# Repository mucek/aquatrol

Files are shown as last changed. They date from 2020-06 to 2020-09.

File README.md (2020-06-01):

# Aquatrol
## Aquarium controller with pH probe, 3-channel LED controller and much more!
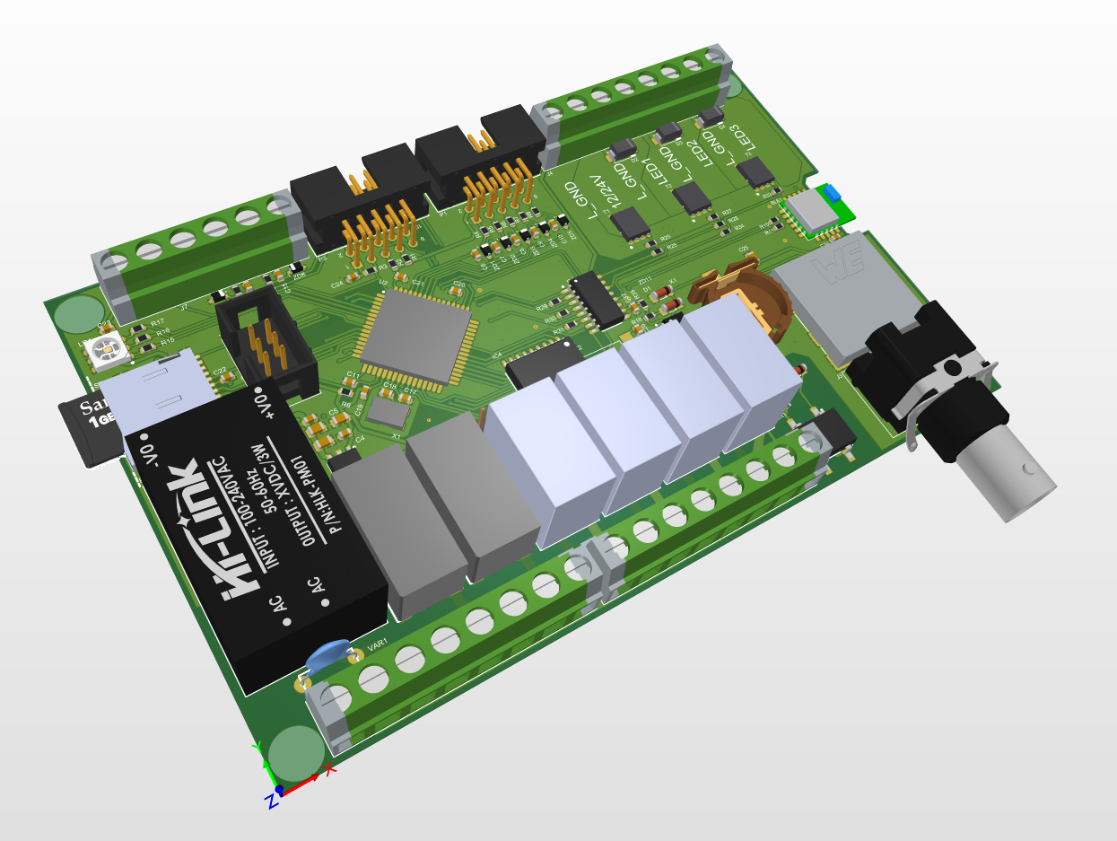
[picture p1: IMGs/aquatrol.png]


## User manuals and quick guide
[User manuals](https://github.com/mucek/aquatrol/blob/master/Docs/_Quickmanual%20aquaTROL.pdf)

[Connection diagram](https://github.com/mucek/aquatrol/blob/master/Docs/Visio-Aquatrol.pdf)

## PCB datasheet
[PCB datasheet (schematics, PCB ...)](https://github.com/mucek/aquatrol/blob/master/PCB/ProductionOutput/Kontroler%20main%20board%201.0_Report.PDF)

## Folder structure:

#### \Android\: Android application (B4A)
#### \Casing\: Casing files
#### \Docs\: Manuals and other documentation
#### \Firmware\: Firmware for the board (Bascom), main program (Aquatrol.hex) and bootloader (BOOT_Aquatrol.hex)
#### \IMGs\: Images
#### \PCB\: PCB project (Altium Designer 20)

## Please write all bugs, feature requests ect. using GitHub's ticketing system! (Issues)

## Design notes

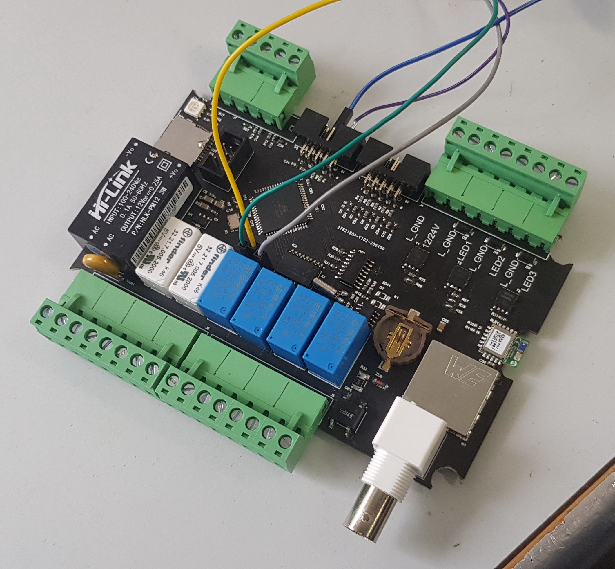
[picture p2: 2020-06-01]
IMGs/2020-05-11 14.08.57.jpg

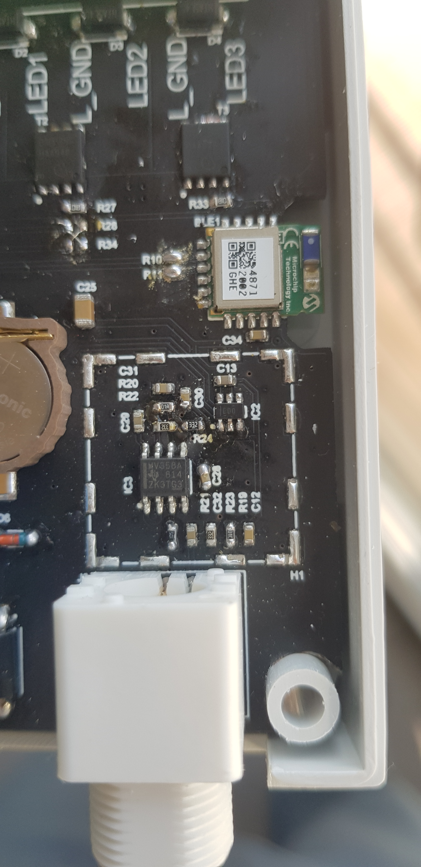
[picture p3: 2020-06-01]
IMGs/2020-05-08 07.53.40.jpg

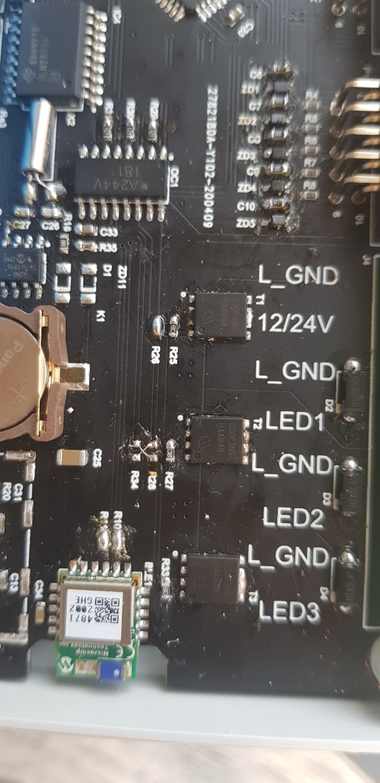
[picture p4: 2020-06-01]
IMGs/2020-05-08 07.53.46.jpg

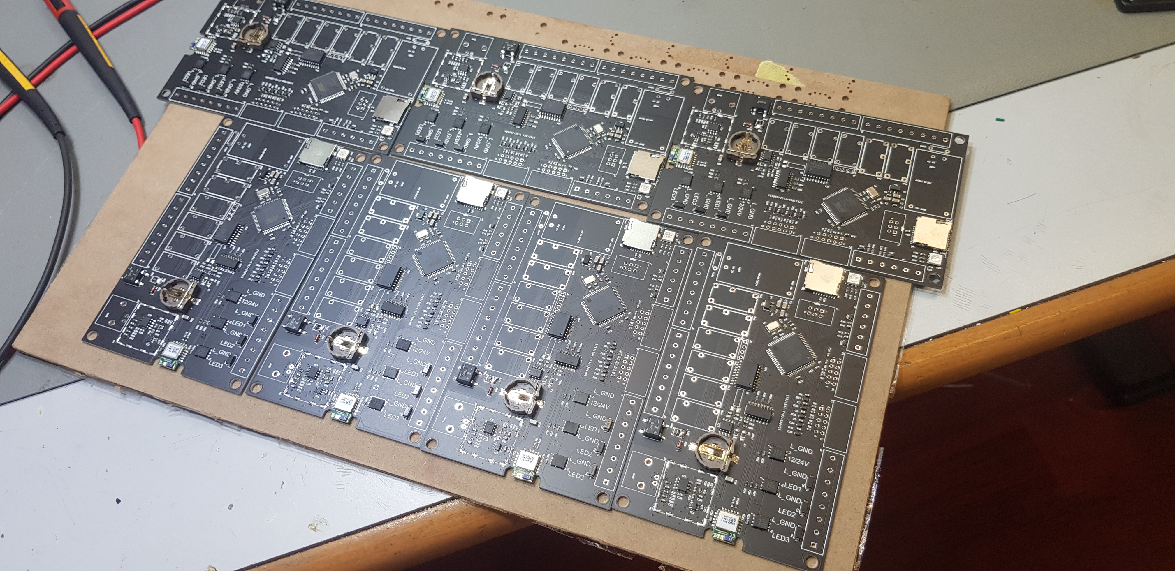
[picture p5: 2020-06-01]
IMGs/2020-05-22 15.17.40.jpg

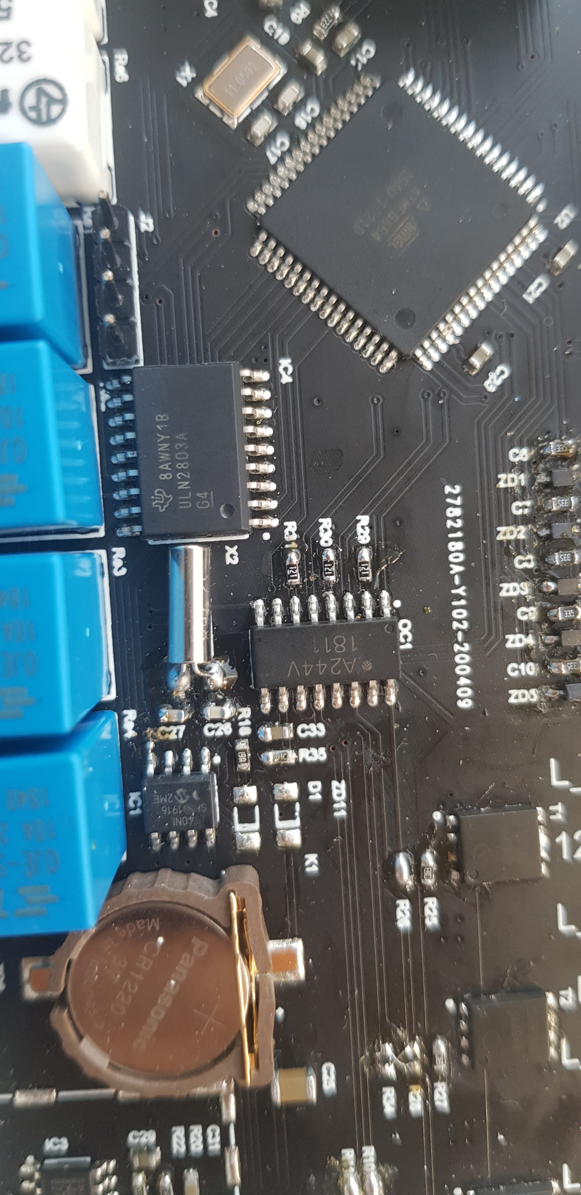
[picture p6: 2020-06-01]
IMGs/2020-05-08 07.53.50.jpg

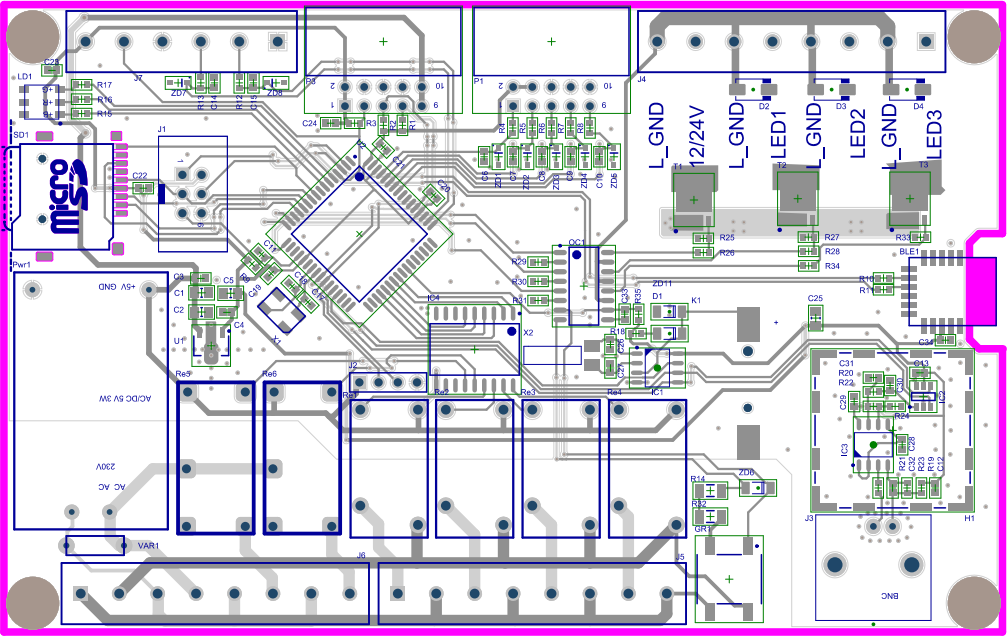
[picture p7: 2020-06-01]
PCB/ProductionOutput/aquatrol.png

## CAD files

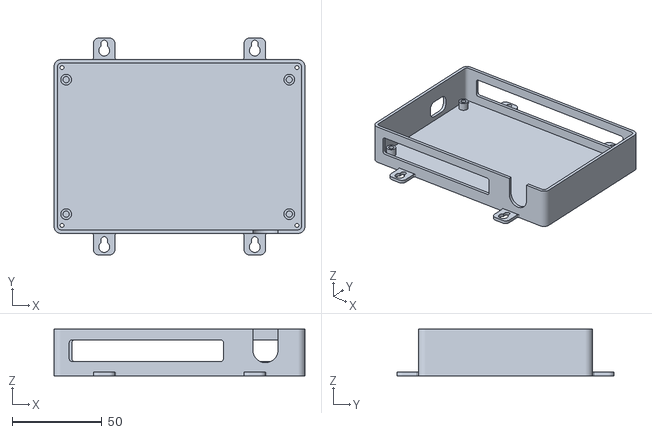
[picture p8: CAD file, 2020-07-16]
Casing/OHISJE-SP-4.stl
140.0 x 121.0 x 26.0

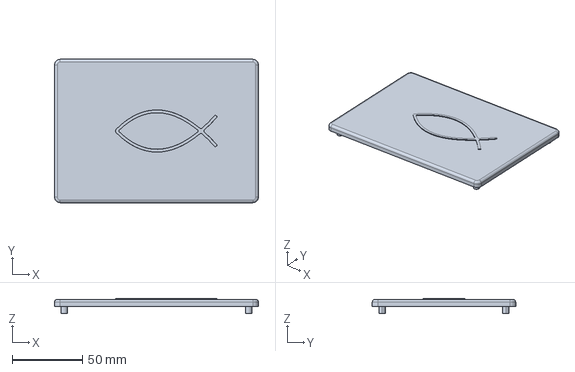
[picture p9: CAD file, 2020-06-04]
Casing/ohisje-zg.stp
145.0 x 102.0 x 10.5 mm

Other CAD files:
Firmware/AquaTrol.obj
Firmware/AquaTrol_HW test.obj
Casing/Z104.dwg
Firmware/BOOT_Aquatrol.obj

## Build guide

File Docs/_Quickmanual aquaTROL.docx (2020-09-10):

# Aquatrol v.1.0 – user manuals

# controller overview

aquaTROL is a dedicated controller for controlling aquarium equipment. Using bluetooth connection it is possible to view status and adjust parameters. Using internal microSD card it is possible also to log data on SD card, adjust settings as well as update firmware.

## Main functions

- LED lights controlling (3 independent channels)
  - Adjustable LED power (255 steps)
  - Sunset and sunrise with adjustable parameters
  - Programmed on/off time, based on internal clock
  - Possible to turn on/off lights using button (night cleaning etc.)
  - Internal clock with backup battery
  - Galvanically seperated outputs, which support 12/24 VDC power supply (external)
  - Max. 4 A / each channel (100 W per channel, 300 W total)
- Heater controlling
  - 230 VAC output to control heater using DS18B20 temperature probe
  - In case of using heater with internal thermostat, we suggest using Aquatrol as main heater controller and adjusting heater's thermostat to 2-3 degrees higher temperature to use it as backup turn-off mechanism.
  - Max. 10 A/230 VAC
- Skimmer controlling
  - 230 VAC output to control turn on skimmer twice per day (adjustable intervals)
  - Max. 10A/230VAC
- CO2 valve controlling using pH probe
  - 230 VAC output for CO2 valve
  - Max. 10A/230VAC
- Filter pumps controlling (2)
  - 2 independent NC channels
  - Max. 6A/230 VAC
  - »FEED« function: when feeding, pump(s) is disabled for a certain period of time (0-999 s)
  - »UPS BACKUP« function: when running on UPS, pumps are switched on alternately in 15 min intervals, so both filters are active and bacterias survive, but power consumption is low.
- 1 auxilary output (10A/230VAC), function will be defined
- Data logging to SD card
  - Data logging on each action; i.e. lights on, CO2 valva off … (/LOG/DATA.TXT)
  - Periodically logging of all parameters to CSV file (/LOG/LOG.TXT), which can be later processed in Excel
- Parameters setup using file on SD card
  - /CONFIG/CONFIG.TXT
- Firmware update using SD card
  - Copy »AquaTrol.hex« file to root folder on SD card
  - Insert card to controller, power on the system and wait 20 s
  - Turn off the controller
  - Remove card and delete file after upgrade

# CONNECTING THE CONTROLLER

Warning! There is a mains voltage on the controller! Be careful and first disconnect the power supply cable before doing anything on the controller itself!

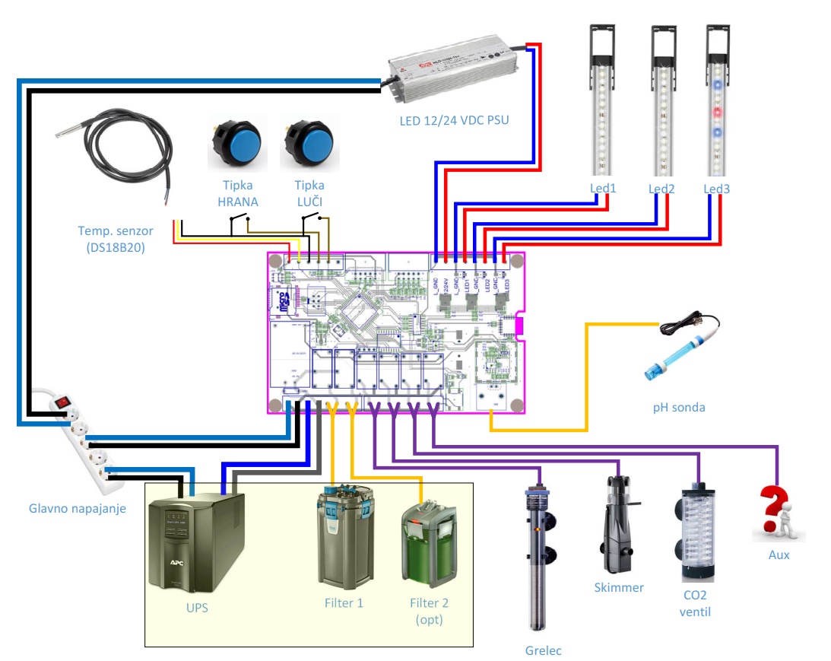
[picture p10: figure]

1) Prepare mains cable 230 VAC. Do not connect cable to the power outlet yet!
2) Prepare mains cable for UPS (if used). UPS is used to power controller logic and both filters. All other devices are powered through mains power and in case that mains is disconnected are shut off.
  a. If UPS is not used, short pins 1+3 and 2+4!

Do not connect cable to the UPS yet!

3) Prepare connectors to all equipment used.
  a. If only one filter is used, connect it to left output (1).
4) Connect LED power supply. Mind the correct polarity! Do not connect cable to the power outlet yet!
5) Connect LED diodes to outputs 1-3. Mind the correct polarity!
6) Connect temperature sensor (if used).
7) Connect buttons (if used).
8) Connect pH probe (if used).
9) Insert microSD card (FAT32).
10) Activate UPS power supply. Controller should turn on (see LED diode on it above SD card).
11) Activate mains power supply (230 VAC).
12) Activate LED power supply.

# PARAMETERS SETUP

Parameters are stored in internal EEPROM memory as well as on SD card. If SD card is inserted, data from SD will always be used and copied to EEPROM as well. If no SD card is present, data from EEPROM will be used.

Disconnect UPS 230 VAC power supply. Remove microSD card and insert it into computer. There is a file CONFIG.TXT in the CONFIG folder with following content:

AquaTROL BASIC SETTINGS

/Edit only values, keep formatting!!!/

_________LED 1:__________

255 - power on (000-255)

000 - power off (000-255)

11:00:00 - on time

19:00:00 - off time

1000 - Dimming Step 1(0100-9999)

_________LED 2:__________

254 - power on (000-255)

001 - power off (000-255)

11:15:00 - on time

18:50:00 - off time

1000 - Dimming Step 2(0100-9999)

_________LED 3:__________

255 - power on (000-255)

002 - power off (000-255)

09:00:00 - on time

20:00:00 - off time

1000 - Dimming Step 3(0100-9999)

_______TEMPERATURE_______

251 - target temperature (x.xx)

_________SKIMMER_________

10:00:05 - on time 1

10:15:05 - off time 1

16:00:06 - on time 2

16:15:06 - off time 2

_________CO2 VALVE_______

6.51 - target pH (x.xx)

________FEED TIME________

300 - feed time in s (xxx)

1 - pumps affected (0,1,2)

LED channel 1 settings (left)

Day power (000-255, 255=100%)

Night power (000-255, 0=off)

Sunrise time (time, when sunrise starts)

Sunset time (time, when sunset starts)

Sunset and sunrise speed (1000 approx 15 min)

LED channel 2 settings (middle)

LED channel 3 settings (right)

Heater target temperature

(hysteresis set to 0,2 degrees Celsius)

Skimmer on time 1

Skimmer off time 1

Skimmer on time 2

Skimmer off time 2

CO2 valve pH setting

(hysteresis set to 0,1 pH)

Filter disable when feeding

Feeding time – filter disabling in seconds

0-disabled, 1-filter 1 only, 2-both filters

You may change all values, but keep in mind, that you must not change formatting (i.e. write 100 instead of 0100 or insert/delete some line(s).

# TIME AND DATE CHANGING (rtc)

Create file TIME.TXT using notepad. Its content should be exactly in following format:

12:32:00 04/06/20 | Time Date

When system will startup, file will be read and RTC time will be updated. File will be deleted automatically.

# pH probe calibration

As pH probes are different and they also degenerate with time, it is reccomended to do a periodical calibration each 3-6 months. However at first use pH probe calibration is neccessary for proper readings!

## Requirements

- Aquatrol & pH probe with BNC connector (obviously 😉)
- A glass of tap water (to clean the probe)
- A pH buffer solution with pH=7,0
- A pH buffer solution with pH=4,0
- Smartphone with terminal (Microchip Bluetooth Data or BLT), that works (shows logs each few seconds)

## A step by step guide

1. Connect the pH probe to BNC
2. Put BNC probe to tap water
3. Connect to Aquatrol using terminal
  - Start the app
  - Select BM 70
  - Scan devices and click Aquatrol_xxxx, when found
  - Wait few seconds and click »Transfer data to device«
  - You shall receive periodical readings from the Aquatrol now into top window
  - Click » Send CR/LF« checkbox
  - Write »c« (small letter!) into send window and click »Send«
  - Follow the onscreen manuals for calibration!
4. Put probe into pH=7,0 buffer solution and wait as requested
5. Put probe into tap water to clean it as requested
6. Put probe into pH=4,0 buffer solution and wait as requested
7. Calibrating is finished, clean probe with tap water before putting it to aquarium!

# Teminal commands (change settings via bluetooth)

By default, parameters from SD card are used. At each system startup, data from SD card are also stored into internal memory, so system is operational also if SD card is not inserted.

Some parameters can also be changed through bluetooth terminal, however they are not stored on the SD card, but on internal memory. In case, that internal memory should be used with SD card present (i.e. for logging), a special command must be sent through terminal as described later.

Use only small letters, text is case sensitive!

Command | Syntax | Description | Example

Lights commands

pH probe
cala | | Start automatic pH probe calibration | cala +CR/LF
cals | | Set manual step for 1 pH | cals=0.1020 +CR/LF
cal7 | | Set manual voltage for pH 7 | cal7=0.8525 +CR/LF
feed | | Start Feed cycle | feed +CR/LF
lamp | | Turn LEDs on/off | lamp +CR/LF
help | | Print out all commands | help +CR/LF
pars | | Print out all parameters | pars +CR/LF

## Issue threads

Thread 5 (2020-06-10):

Indikacija ročnega vklopa/izklopa LED in hranjenja

mucek, 2020-06-10:
RGB LED indicira vklop/izklop funkcije:
LED: zelena vklop, oranžna izklop
HRANJENJE: rdeča LED, dokler so pumpe izklopljene

mucek, 2020-06-10:
Narejeno  1 , 0 , 501

Closed 2020-06-10.

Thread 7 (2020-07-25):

Vprašajčki v Terminal Feedu

umetnic, 2020-07-25:
FW: v.1.0.605
**LOG.TXT**; _Se zdi v redu..._

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

**[Microchip Bluetooth Data Export](https://play.google.com/store/apps/details?id=com.microchip.bluetooth.data):**
_Vprašajčki na drugih točkah kot v naslednjem app-u_
video: https://www.youtube.com/embed/q5NsGTYWXBU
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

**[Serial Bluetooth Terminal Export](https://play.google.com/store/apps/details?id=de.kai_morich.serial_bluetooth_terminal):**
_Vprašajčki so konstantni znotraj enega connectiona, pri naslednjem pa so drugje.._
08:48:56.577 Connecting to AquaTrol_C1E7 ...
08:49:01.802 Connection failed: gatt status 133
08:49:06.714 Connecting to AquaTrol_C1E7 ...
08:49:11.887 Connection failed: gatt status 133
08:49:21.716 Connecting to AquaTrol_C1E7 ...
08:49:24.901 **Connected**
08:49:25.896
08:49:27.186
08:49:27.248
08:49:27.248 25/07/20 08:53:09
08:49:27.248 Fltr�� ^@s:0(t=0)
08:49:27.248 Fltr2_dis:0(t=0)
08:49:27.248 Heater:0(248/252)
08:49:27.248 Skimmer:0 10:00:00/10:15:00, 16:00:00/16:15:00
08:49:27.248 CO2 valve:1(6.5000)
08:49:27.248 Aux:0
08:49:27.248 Led1:0/255, 255@11:00:00/0@19:00:00
08:49:27.307 Led2:0/255, 255@11:15:00/0@18:50:00
08:49:27.307 Led3:0/255, 255@09:00:00/0@20:00:00
08:49:27.307
08:49:27.307 pH :7.6006(U=1.7139V)
08:49:27.307 Temp :253oC
08:49:27.307 AC OK:1
08:49:27.366 IN1 feed:0(300s)
08:49:27.366 IN2 light:0(step 1000)
08:49:28.205
08:49:29.196
08:49:30.216
08:49:31.241
08:49:31.298
08:49:31.298 25/07/20 08:53:13
08:49:31.298 Fltr�� ^@s:0(t=0)
08:49:31.298 Fltr2_dis:0(t=0)
08:49:31.298 Heater:0(248/252)
08:49:31.298 Skimmer:0 10:00:00/10:15:00, 16:00:00/16:15:00
08:49:31.298 CO2 valve:1(6.5000)
08:49:31.298 Aux:0
08:49:31.298 Led1:0/255, 255@11:00:00/0@19:00:00
08:49:31.359 Led2:0/255, 255@11:15:00/0@18:50:00
08:49:31.359 Led3:0/255, 255@09:00:00/0@20:00:00
08:49:31.359
08:49:31.359 pH :7.6006(U=1.7139V)
08:49:31.359 Temp :253oC
08:49:31.359 AC OK:1
08:49:31.417 IN1 feed:0(300s)
08:49:31.417 IN2 light:0(step 1000)
...
08:50:01.418
08:50:02.441
08:50:03.428
08:50:04.448
08:50:04.510
08:50:04.510 25/07/20 08:53:47
08:50:04.510 Fltr�� ^@s:0(t=0)
08:50:04.510 Fltr2_dis:0(t=0)
08:50:04.510 Heater:0(248/252)
08:50:04.510 Skimmer:0 10:00:00/10:15:00, 16:00:00/16:15:00
08:50:04.510 CO2 valve:1(6.5000)
08:50:04.510 Aux:0
08:50:04.510 Led1:0/255, 255@11:00:00/0@19:00:00
08:50:04.569 Led2:0/255, 255@11:15:00/0@18:50:00
08:50:04.569 Led3:0/255, 255@09:00:00/0@20:00:00
08:50:04.569
08:50:04.569 pH :7.5957(U=1.7145V)
08:50:04.569 Temp :253oC
08:50:04.569 AC OK:1
08:50:09.728 **Connection lost**
08:58:31.988 Connecting to AquaTrol_C1E7 ...
08:58:34.949 **Connected**
08:58:35.627 tr2_dis:0(t=0)
08:58:35.627 Heater:0(248/252)
08:58:35.627 Skimmer
08:58:36.615
08:58:37.636
08:58:38.627
08:58:38.689
08:58:38.689 25/07/20 09:02:21
08:58:38.689 Fltr1_dis:0(t=0)
08:58:38.689 Fltr2_dis:0(t=0)
08:58:38.689 Heater:0(248/252)
08:58:38.689 Skimmer:0 10:00:00/10:15:00, 16:00:00/16:15:00
08:58:38.689 CO2 valve:1(6.5000)
08:58:38.689 Aux:0
08:58:38.689 Led1:0/255, 255@11:00:00/0@1�� ^@:00
08:58:38.749 Led2:0/255, 255@11:15:00/0@18:50:00
08:58:38.749 Led3:29/255, 255@09:00:00/0@20:00:00
08:58:38.749
08:58:38.749 pH :7.5907(U=1.7150V)
08:58:38.749 Temp :253oC
08:58:38.749 AC OK:1
08:58:38.807 IN1 feed:0(300s)
08:58:38.807 IN2 light:0(step 1000)
08:58:39.646
08:58:40.666
08:58:41.687
08:58:42.676
08:58:42.738
08:58:42.738 25/07/20 09:02:25
08:58:42.738 Fltr1_dis:0(t=0)
08:58:42.738 Fltr2_dis:0(t=0)
08:58:42.738 Heater:0(248/252)
08:58:42.738 Skimmer:0 10:00:00/10:15:00, 16:00:00/16:15:00
08:58:42.738 CO2 valve:1(6.5000)
08:58:42.738 Aux:0
08:58:42.738 Led1:0/255, 255@11:00:00/0@1�� ^@:00
08:58:42.799 Led2:0/255, 255@11:15:00/0@18:50:00
08:58:42.799 Led3:30/255, 255@09:00:00/0@20:00:00
08:58:42.799
08:58:42.799 pH :7.5907(U=1.7150V)
08:58:42.799 Temp :253oC
08:58:42.799 AC OK:1
08:58:42.857 IN1 feed:0(300s)
08:58:42.857 IN2 light:0(step 1000)
...
08:58:59.479 25/07/20 09:02:42
08:58:59.479 Fltr1_dis:0(t=0)
08:58:59.479 Fltr2_dis:0(t=0)
08:58:59.479 Heater:0(248/252)
08:58:59.479 Skimmer:0 10:00:00/10:15:00, 16:00:00/16:15:00
08:58:59.479 CO2 valve:1(6.5000)
08:58:59.479 Aux:0
08:58:59.479 Led1:0/255, 255@11:00:00/0@1�� ^@:00
08:58:59.539 Led2:0/255, 255@11:15:00/0@18:50:00
08:58:59.539 Led3:33/255, 255@09:00:00/0@20:00:00
08:58:59.539
08:58:59.539 pH :7.5997(U=1.7140V)
08:58:59.539 Temp :253oC
08:58:59.539 AC OK:1
08:58:59.597 IN1 feed:0(300s)
08:58:59.597 IN2 light:0(step 1000)
08:59:00.158 Disconnected

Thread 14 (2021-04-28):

Failsafe, ko se kontroler obesi

umetnic, 2021-04-28:
Včeraj je PI iz neznanega razloga (pustil sem ga čisto pri miru) zmrznil. Ko sem bežno pogledal na tab-e v Firefoxu, nisem opazil timestamp-a v ph-grafu. Zadnji del dneva je bil torej zmrznjen.
Predlagam torej nek fail safe scenarij, da recimo Co2 solenoid ne ostane odprt itd..vkolikor to že ni na samem kontrolerju.
Pri integraciji z HASS, bi lahko HASS javil, če so odčitane vrednosti dalj časa fixne recimo.
Po delujočih LEDicah na kontrolerjih, bi dejal, da je kontroler še vedno deloval normalno, zgolj PI se je obesil. Po resetu deluje normalno naprej.
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

mucek, 2021-04-28:
RPI nima veze s samim aktivnim delovanjem Aquatrola – ravno nestabilnost RPIja in višjenivojskih OSov mi je bil glavni razlog, da je low level krmiljenje vse na ravni RTOS na procesorju. Po domače: če RPI crkne, vse krmiljenje itd. deluje bp. in neodvisno od RPIja.

LP, g

Od: umetnic ***@***.***>
Poslano: Wednesday, 28 April 2021 09:07
Za: mucek/aquatrol ***@***.***>
Kp: Subscribed ***@***.***>
Zadeva: [mucek/aquatrol] Failsafe, ko se kontroler obesi (#14)

Včeraj je PI iz neznanega razloga (pustil sem ga čisto pri miru) zmrznil. Ko sem bežno pogledal na tab-e v Firefoxu, nisem opazil timestamp-a v ph-grafu. Zadnji del dneva je bil torej zmrznjen.
Predlagam torej nek fail safe scenarij, da recimo Co2 solenoid ne ostane odprt itd..vkolikor to že ni na samem kontrolerju.
Pri integraciji z HASS, bi lahko HASS javil, če so odčitane vrednosti dalj časa fixne recimo.
Po delujočih LEDicah na kontrolerjih, bi dejal, da je kontroler še vedno deloval normalno, zgolj PI se je obesil. Po resetu deluje normalno naprej.
 <https://user-images.githubusercontent.com/30912764/116360213-fd1d7f80-a7ff-11eb-96b5-efd6603d4151.png>

—
You are receiving this because you are subscribed to this thread.
Reply to this email directly, view it on GitHub <https://github.com/mucek/aquatrol/issues/14> , or unsubscribe <https://github.com/notifications/unsubscribe-auth/ADZBUGFF2XLJGWYD54LKZXTTK6XYVANCNFSM43WOO2VA> .

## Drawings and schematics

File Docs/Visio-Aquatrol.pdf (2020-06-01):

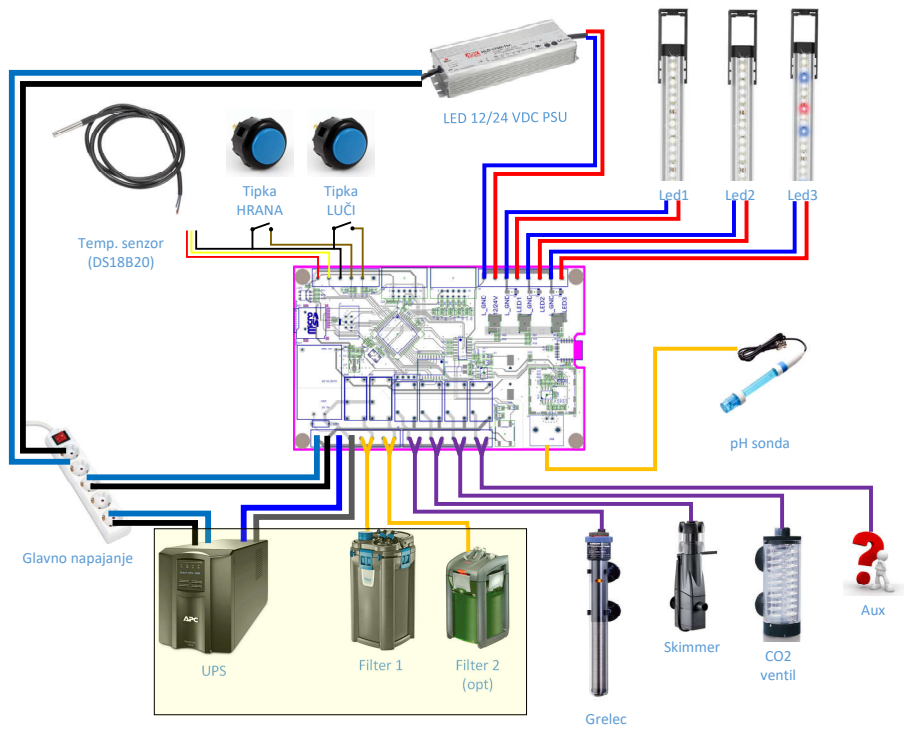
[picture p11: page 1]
UPS; Glavno napajanje; Filter 1; Filter 2; (opt); Grelec; Skimmer; ventil; Temp. senzor (DS18B20); Tipka; Led1; Led2; Led3; HRANA; Tipka LUČI; Aux; pH sonda

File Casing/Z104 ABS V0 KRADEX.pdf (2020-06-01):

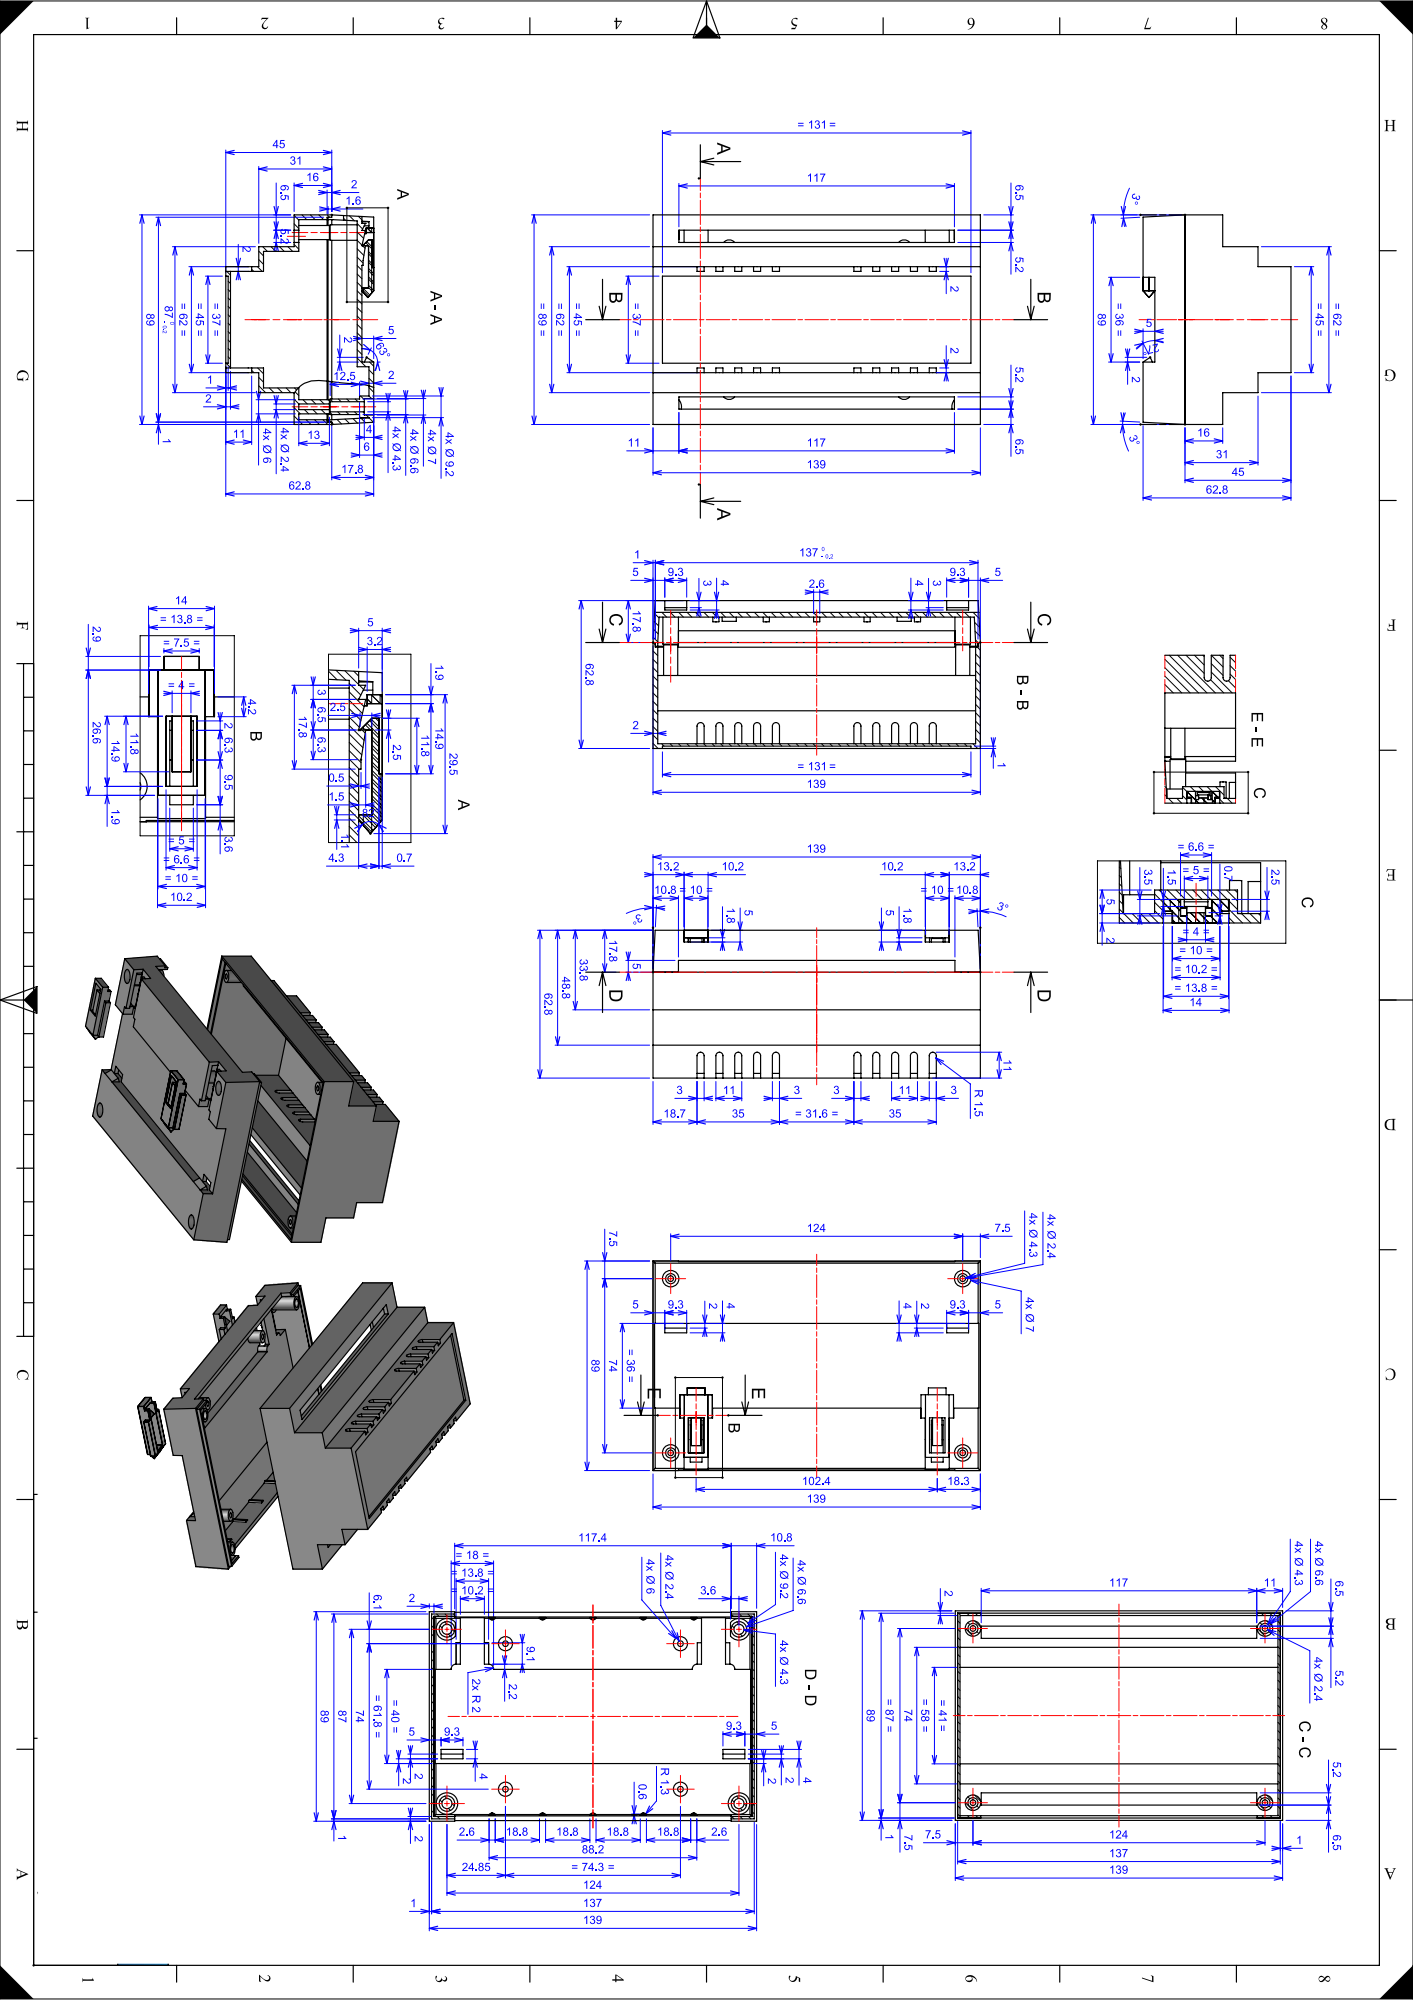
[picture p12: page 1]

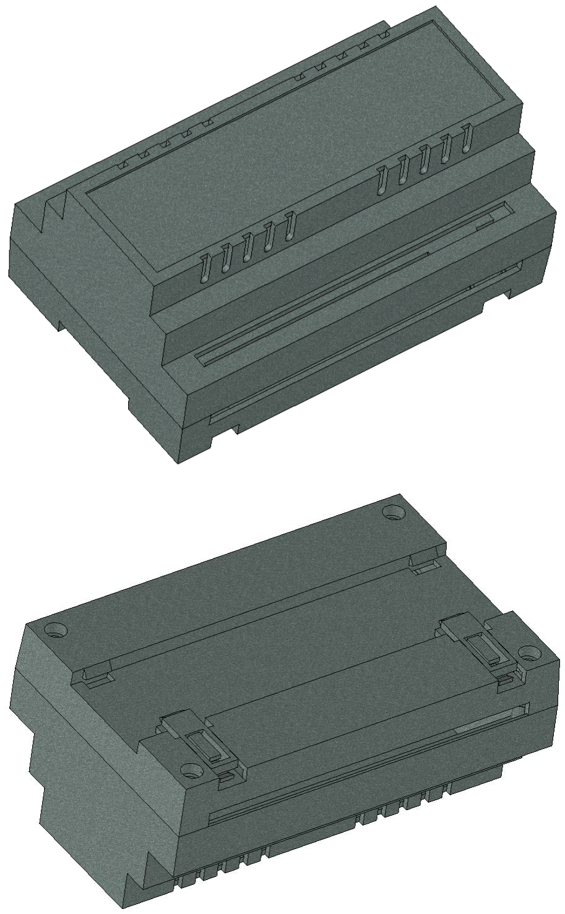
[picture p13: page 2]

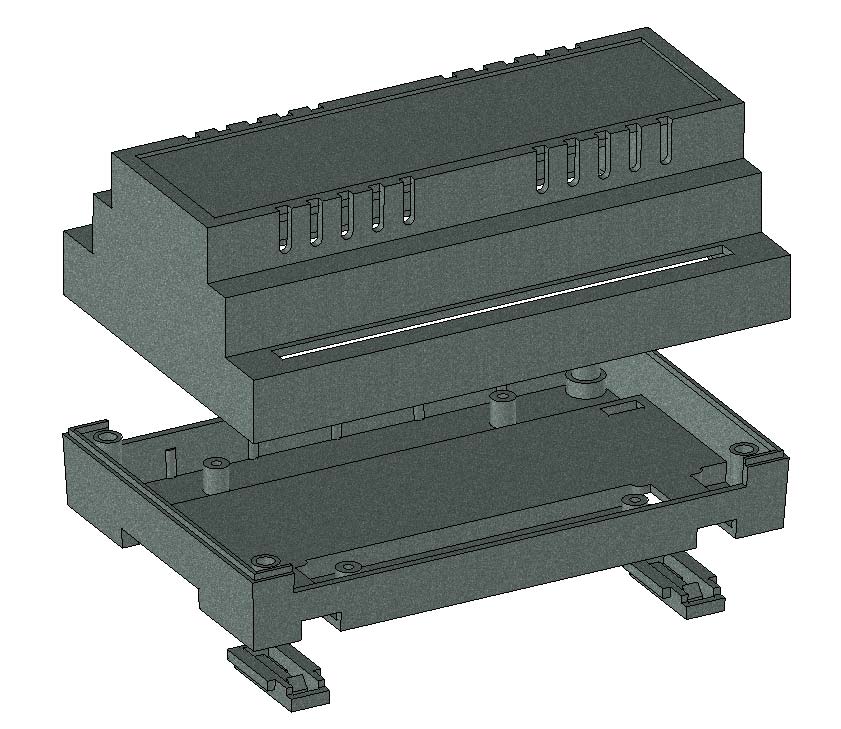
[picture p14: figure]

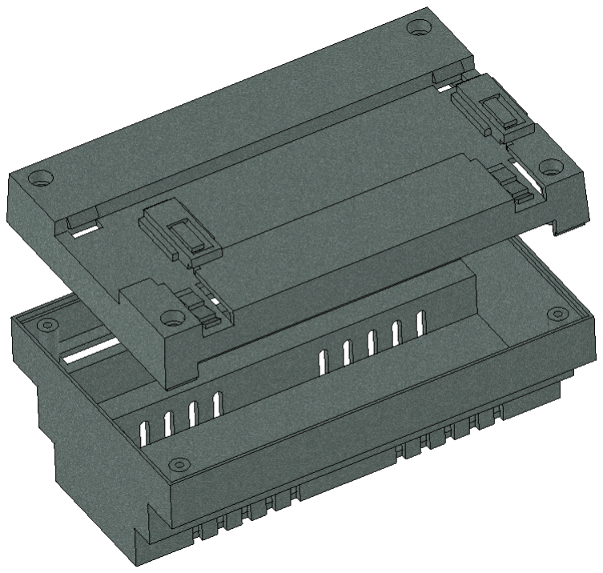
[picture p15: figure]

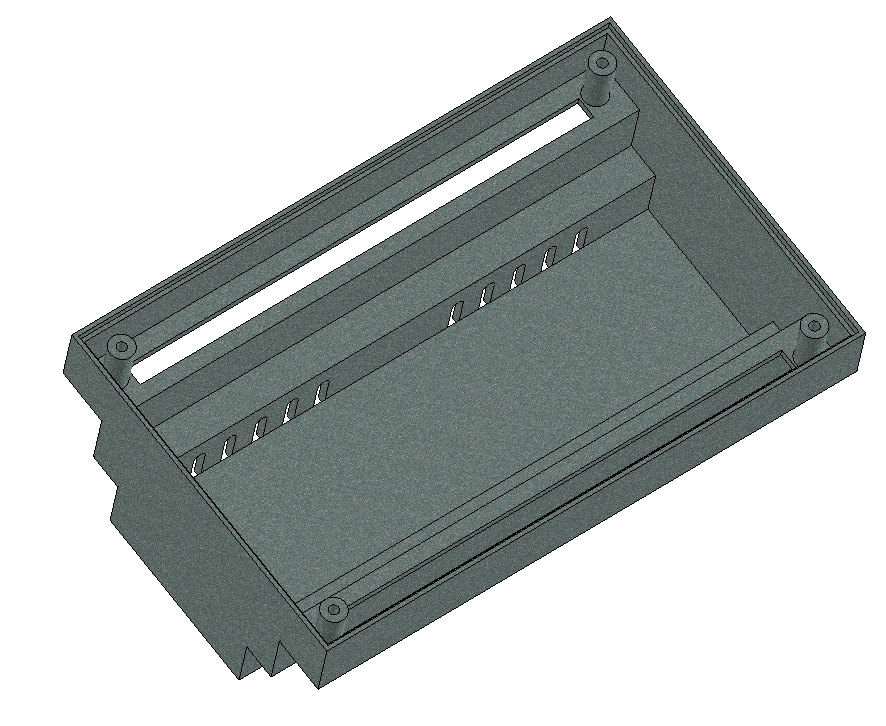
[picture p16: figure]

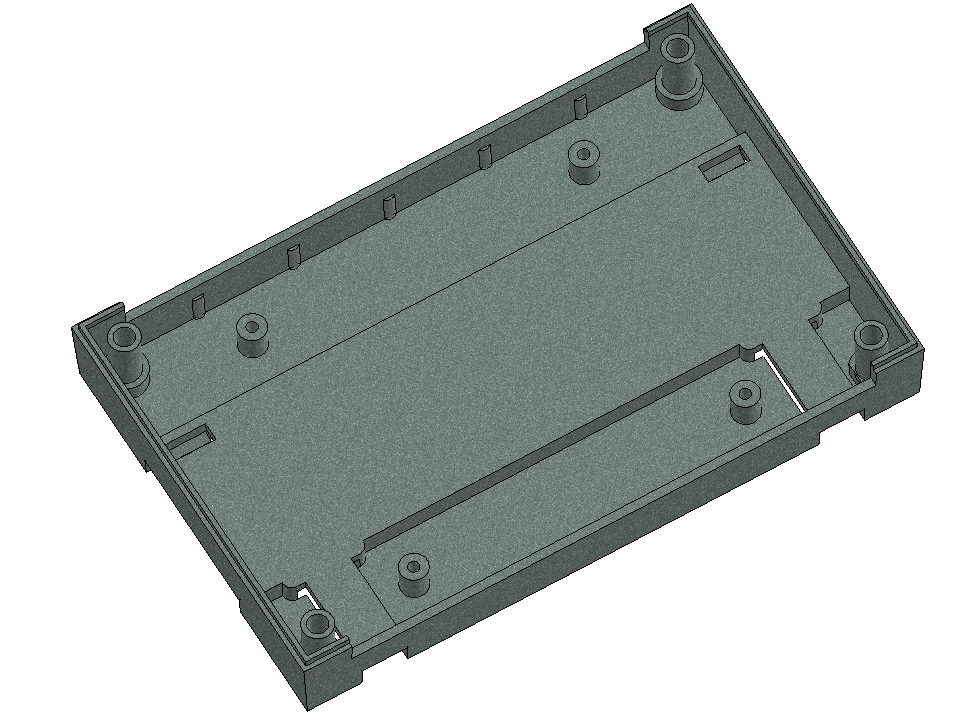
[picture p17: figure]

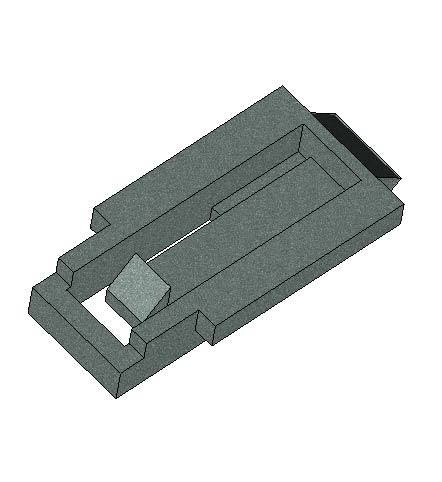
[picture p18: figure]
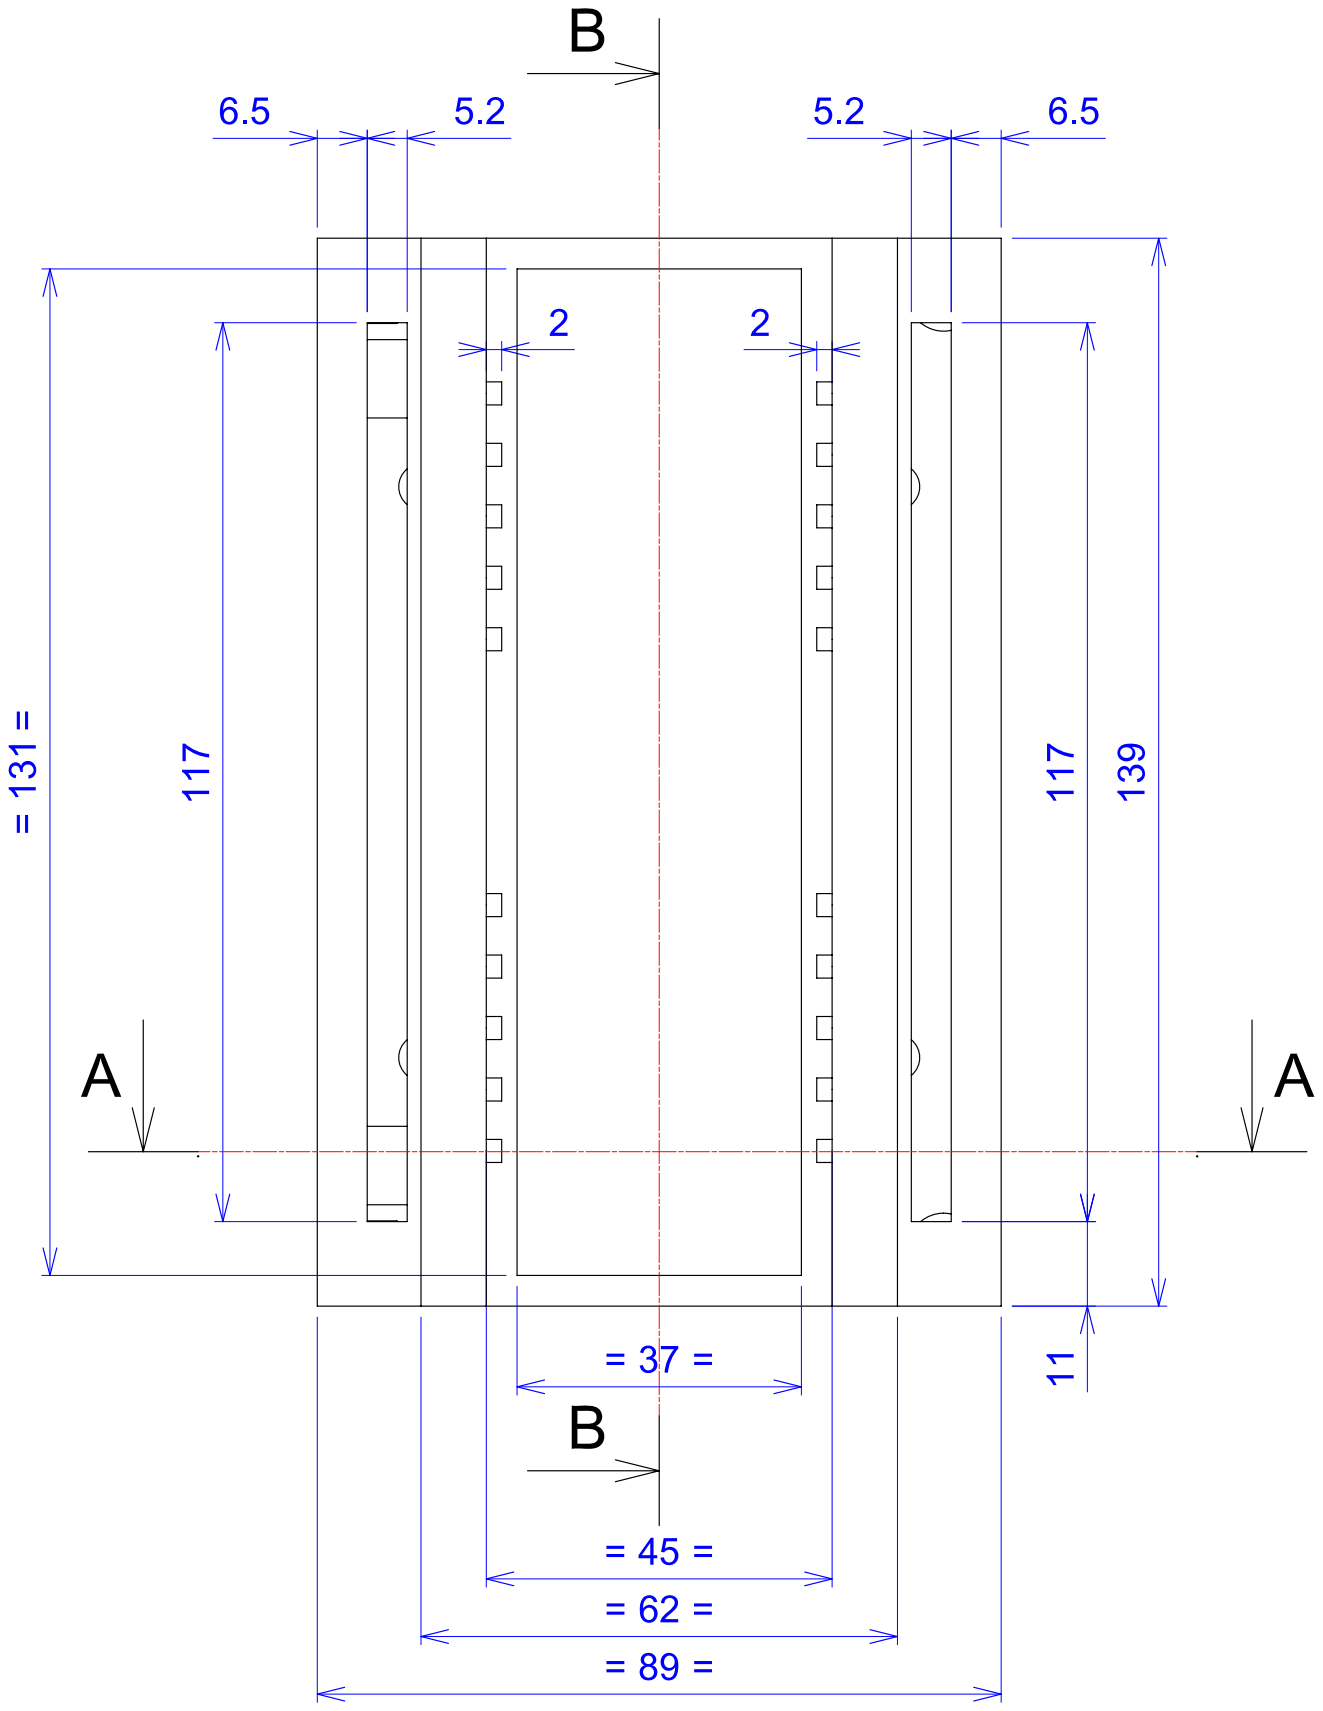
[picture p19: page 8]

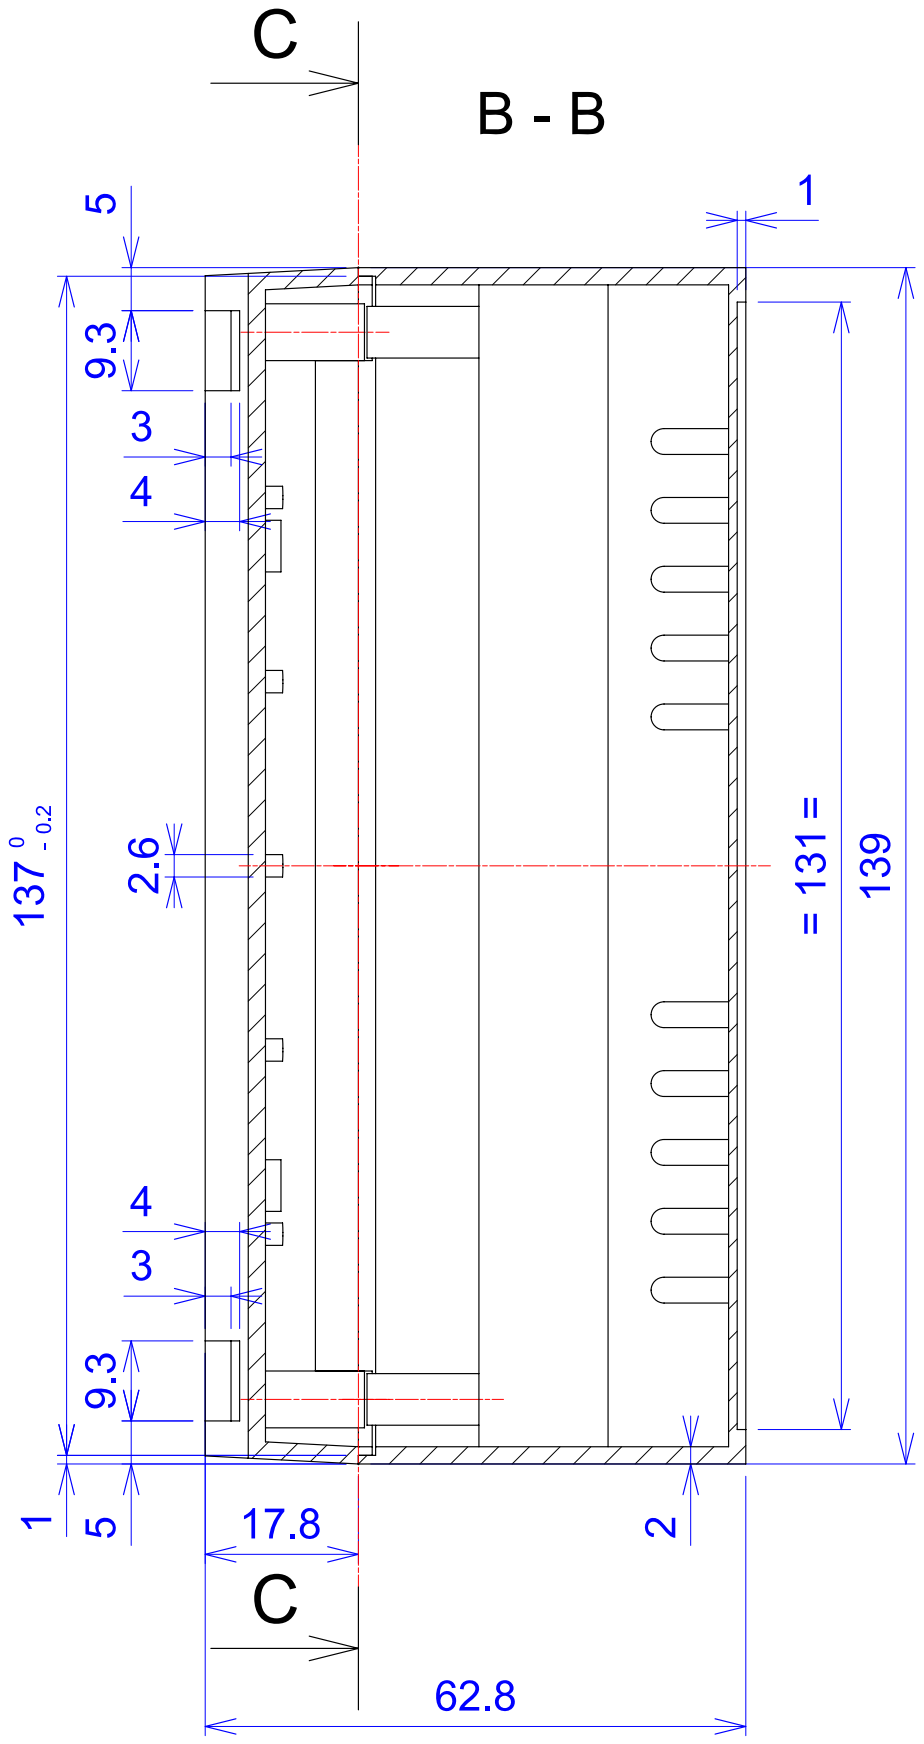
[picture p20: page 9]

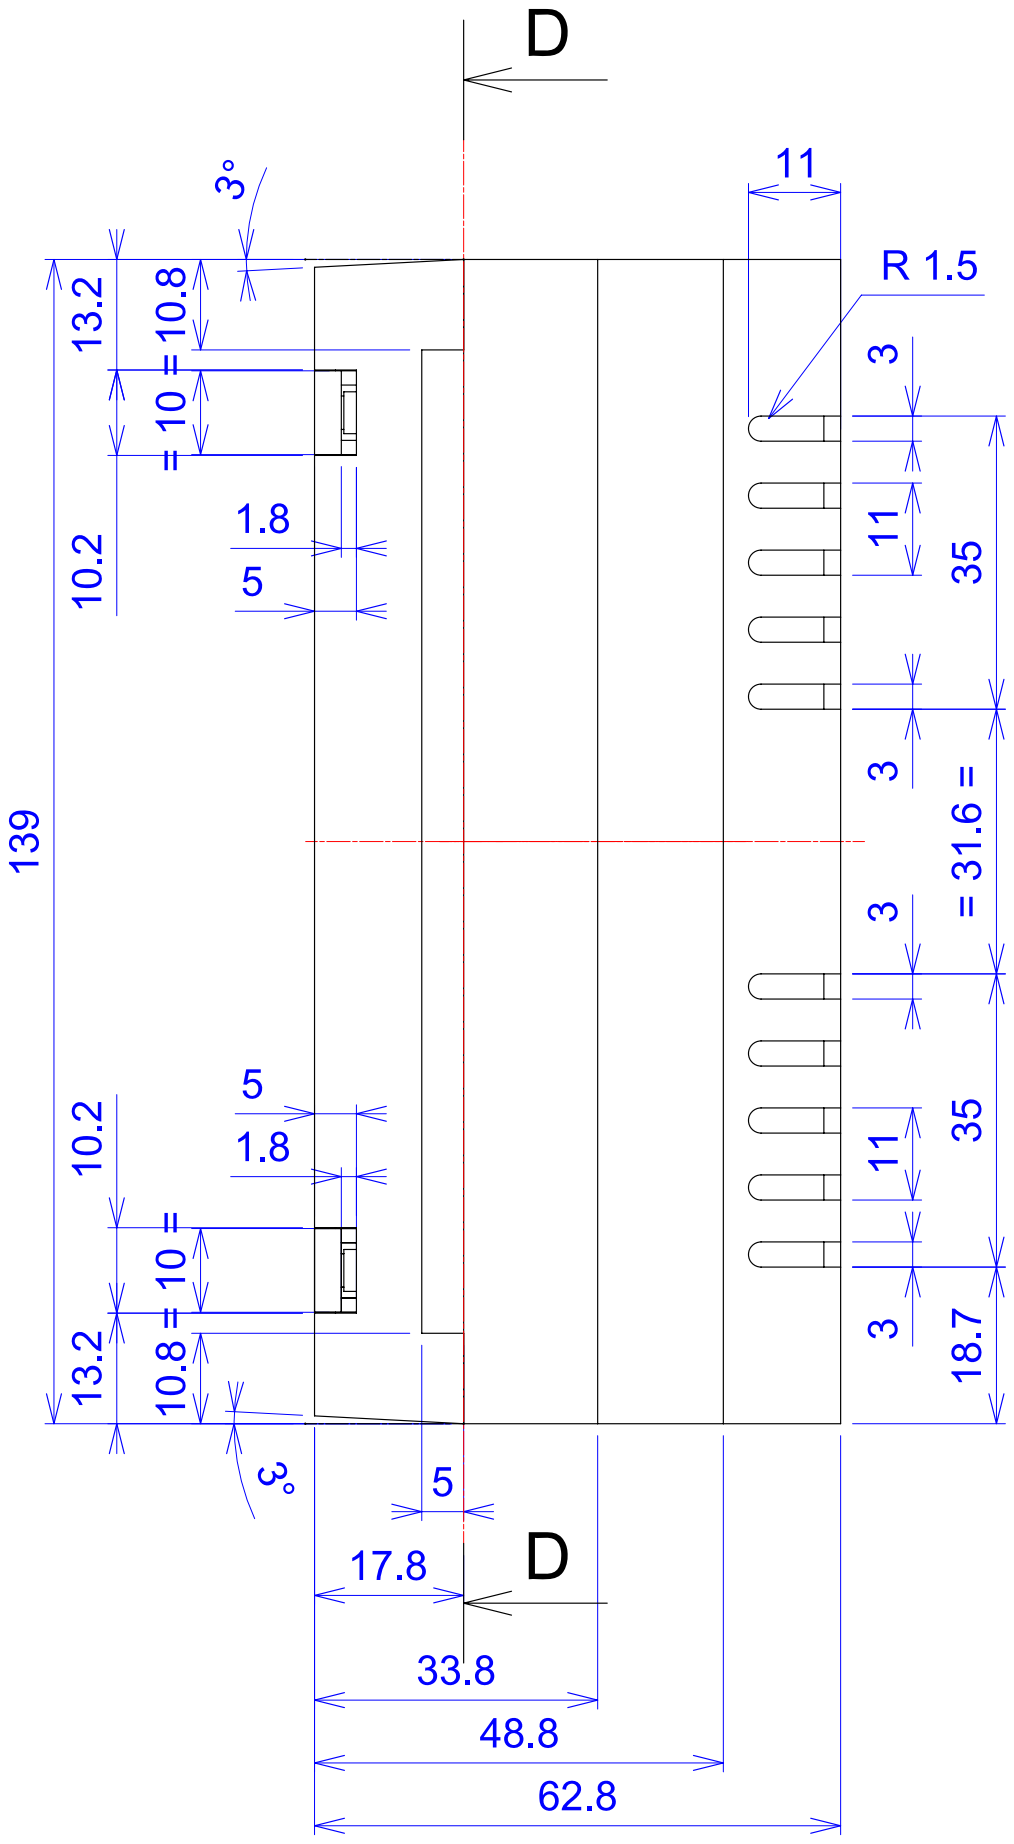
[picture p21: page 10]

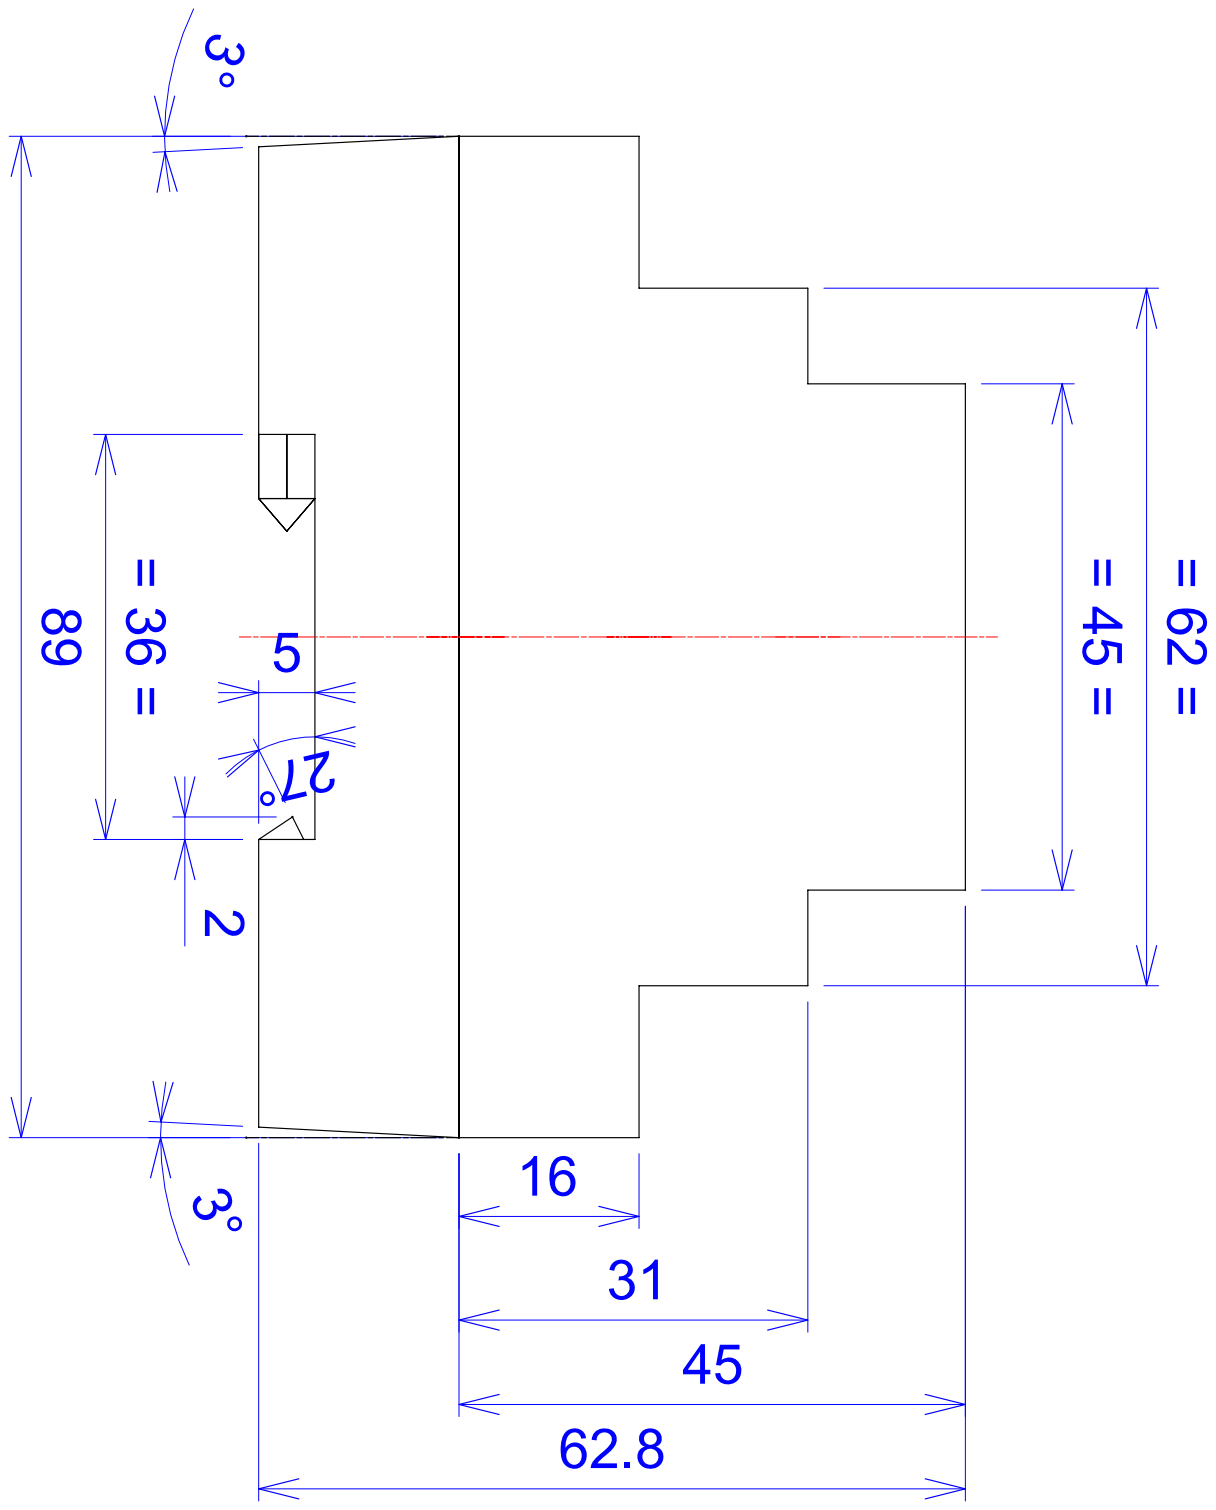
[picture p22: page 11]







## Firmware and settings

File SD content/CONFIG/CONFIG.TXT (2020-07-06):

AquaTROL BASIC SETTINGS
/Edit only values, keep formatting!!!/

_________LED 1:__________
255 - power on (000-255)
000 - power off (000-255)
11:00:00 - on time
19:00:00 - off time
1000 - Dimming Step 1(0100-9999)
_________LED 2:__________
255 - power on (000-255)
000 - power off (000-255)
11:15:00 - on time
18:50:00 - off time
1100 - Dimming Step 1(0100-9999)
_________LED 3:__________
255 - power on (000-255)
000 - power off (000-255)
09:00:00 - on time
20:00:00 - off time
1200 - Dimming Step 1(0100-9999)

_______TEMPERATURE_______
250 - target temperature (xxx=xx.x)

_________SKIMMER_________
10:00:00 - on time 1
10:15:00 - off time 1
16:00:00 - on time 2
16:15:00 - off time 2

_________CO2 VALVE_______
6.50 - target pH (x.xx)

________FEED TIME________
300 - feed time in s (xxx)
1 - pumps affected (0,1,2)

_____CO2 calibration______
1.8577 - ph_calib_401
1.5317 - ph_calib_686
0.1144 - ph_calc1

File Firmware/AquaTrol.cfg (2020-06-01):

[COMPILER-CHIP]
Chip=2313def.dat
XRAM=0
Waitstate=0
XA=0
Stacksize=40
Framesize=32
Sstack=16
[COMPILER-OUTPUT]
Report vars=0
Optimize=0
Binary File=1
Hexadecimal File=1
Report File=1
Debug File=1
Error File=1
ASM File=0
LST File=0
OBJ File=1
SWAP File=0
[COMPILER-COMMUNICATION]
Baudrate=9600
Frequency=4000000
[COMPILER-I2C]
Scl=0
Sda=0
[COMPILER-LCD]
DB7=PORTB.7
DB6=PORTB.6
DB5=PORTB.5
DB4=PORTB.4
E=PORTB.3
RS=PORTB.2
LCD=1
BUS mode=0
DATA mode=0
LCD address=C000
LCD-RS=8000
[COMPILER-MISC]
Size Warning=0
1wire=PORTB.0
[COMPILER-SPI]
HW SPI=0
SPICLOCK=13
SPISS=13
SPIMOSI=14
SPIMISO=15

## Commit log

2020-06-01 First upload
    [AquaTrol.cfg, AquaTrol.obj, BLE.SchDoc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]
2020-06-04 Ohišje
    [OHISJE-SP.stp, ohisje-zg.stp]
2020-06-17 FW updates
    [AquaTrol.obj]
2020-07-06 Dodano poglavje o kalibraciji
    [AquaTrol.obj, AquaTrol_HW test.obj, CONFIG.TXT]
2020-07-16 Firmware update (bug on LED channel 2)
    [AquaTrol.obj, OHISJE-SP-4.stl, OHISJE-SP.stp]
2020-07-20 Fixed some minor bugs on display etc.
    [AquaTrol.obj]
2020-07-22 Dodano krmiljenje LED preko BT
    [AquaTrol.obj]
2020-07-27 Added commands over BT terminal: help - show commands with descriptions pars - display parameters lamp - turn lamp on/off cala - start automatic pH calibration routine cal7 - set manual voltage for p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
    [AquaTrol.obj]
